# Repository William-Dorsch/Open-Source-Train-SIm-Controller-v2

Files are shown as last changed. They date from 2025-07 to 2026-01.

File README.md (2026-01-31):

# Open-Source-Train-SIm-Controller-v2

After 9 months I finally made a custom train sim controller I'm happy with, so here's a framework on how to build your own

Attached in this repo are both the files (stl and fbx) of my current design, as well as the scripts neccesary to make them work
(and perhaps documentation on how to make your own scripts for your own projects in the future)

### PRELIMINARY BUILD GUIDE ###
https://docs.google.com/document/d/1KSgfsF_5sMxbXlPAzv2AgdFZr4h-Y06j3LuT_041sC8/edit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<br>

# Hardware
You can either use my current design (based off of a North American desktop setup), or venture into CAD and make your own
FOr my design, you will need the following materials:<br/>
- Arduino Leonardo (or anything that has the usb serial whatever interface) <br/>
- Breadboard, jumper wires, other miscellanious wires to connect things (i use 30 gauge, anything smaller tha 18 could probably work) <br/>
- 50 #4 1/2" screws to be safe (you can buy two boxes of 25 from Ace for 5 bucks<br/>
- 1 6mm ball bearing <br/>
- a couple pen springs will need to be sacrificed, 13mm length<br/>
- 4 5x2mm magnets are necessary for the reverser<br/>
- 4 potentiometers (digikey part #  PDB12-H4301-103BF-ND, I suggest buying a couple spares in case something goes wrong while oldering (ask me how I know))<br/>
- 1 cherry MX brown switch (you can find a pack of them for cheap on Amazon, this is for the bail off, if you don't use bail off then you don't need this)<br/>
- black filament for the housing, need like 600g of that, then you can use whatever other colors you want.  Shouldn't be more than a spool total for the other parts, I use light gray for the handles, gray for the underframe, and gold to fake the brass brake valve parts<br/>
- A printer with a 256cm cubed build volume.  It will get really tricky if you don't, the throttle housing barely fit on my printer (Bambu P1S) <br/>
- some small gauge wire to connect to the potentiometers, the rest is up to you to make<br/>
- a soldering iron<br/>
- some electrical tape (used for friction on the independent brake)<br/>
- something to be used as a counterweight on the levers (I used pinewood derby car weights and pennies, and just hot glued these in place)<br/>

You only need to print 1 of all the parts, EXCEPT FOR THE FOLLOWING<br/>
- 5x axleSupportTall.stl<br/>
- 3x potentiometerHolderTall.stl<br/>
- 2x reverserAxleSupport<br/>

You'll also need to print a reverser, such as this one: (print at 95% scale) https://makerworld.com/en/models/919480-locomotive-reverser#profileId-881394<br/>
(huge credit to this design it is exactly what I was looking for)<br/>
And you'll need 2 printed m5 bolts to allow the throttle and independent brake handles to pivot, such as: https://www.printables.com/model/48364-3d-printable-m5-hex-screw-and-nut

There are some images attached to show how to assemble it, i think you'll be able to figure it out.

# Software
There are a variety of scripts included with this project<br/>
- an arduino sketch to pass data over the serial<br/>
- an arduino keybind-based sketch (for RSU)<br/>
- a python script to interface with the run8 UDP<br/>
- a python script to send the serial data over a local TCP server, paired with a c# .exe to interface with train sim classic<br/>
So you will need the latest version of python installed on your computer, as well as the arduino IDE.

To use it with run8, load the serialInterface arduino file, and run the run8 python script.  Ensure the com port is set correctly in the python script (use VScode or whatever to edi tit)<br/>
To use with TSC, load the serialInterface arduino file, run the TSCinterface python script, and run the code from Program.cs via visual studio.  I'll get an exe in there eventually, again ensure the com port in python is set correctly<br/>
To use it with RSU, just load the RSU arduino script and that's it.

NOTE: you will need the serial and socket libraries for python.  Get them by running the following in your command prompt: <br/>
>pip install serial <br/>
>pip install socket <br/>

NOTE: The TSC script is currently programmed to be used with the Surliner CC Enhancement Pack.  The ControlIDs change from locomotive to locomotive.  Use the function GetControllerList(); to return the list of controls for your specific locomotive.  The index begins at 0, count up from there for the ID of each control.  Plug those into the variables at the top of the script.
If you run it from Visual Studio, you will need the NuGet System.IO.ports package installed (right click the project and go to manage NuGet packages in the solution explorer)

## Calibration
- The values in the arduino script are hard-coded but can be changed<br/>
- For the throttle, note the output from the throttle potentiometer at each notch, and put that into the notch centers array.  If the value varies, add a piece of electrical tape on the potentiometer to avoid wiggle between it and the axle<br/>
- for the dynamic brake, note the value right after the notch, and the value while fuily applied.  Use those in the mapping function.<br/>
- For the automatic brakes, you need to note the values at release, minimum application, full service, suppression, handle off, and emergency (the 6 notches).  Plug in the values from there.<br/>
- FOr the independent brakes, just note the fully released as well as the fully applied values, and apply those to the mapping function<br/>
- For the reverser, note the center and fwd / rvs values.  Choose something halfway between the center and extremes to plug into the function.<br/>

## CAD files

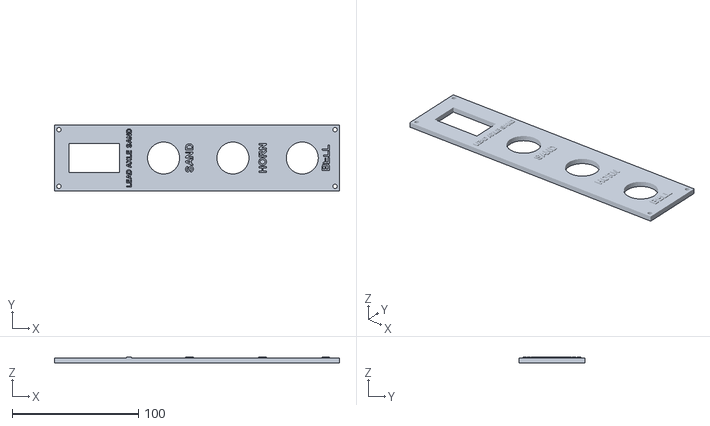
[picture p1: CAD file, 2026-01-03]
3d files/buttons/mainButtonPlate.stl
226.0 x 52.0 x 5.00

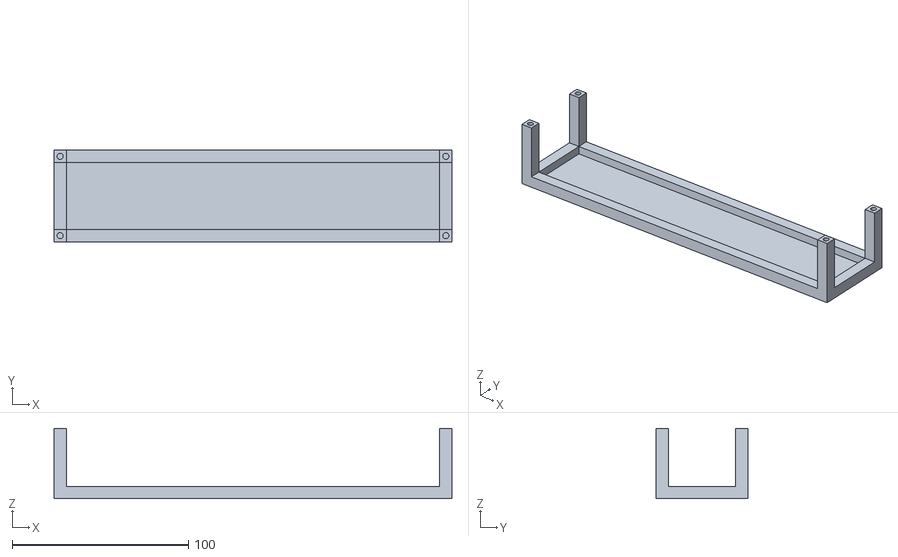
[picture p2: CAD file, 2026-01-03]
3d files/buttons/mainButtonbase.stl
226.0 x 52.0 x 39.9

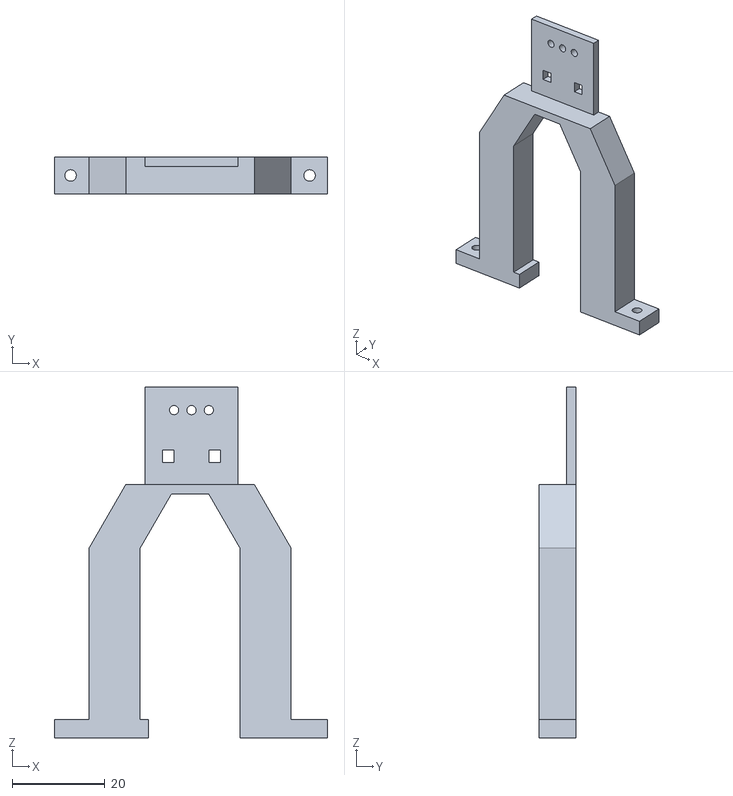
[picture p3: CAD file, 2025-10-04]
3d files/brake assembly/2x potentiometerHolderTall (1).stl
59.0 x 7.99 x 75.8

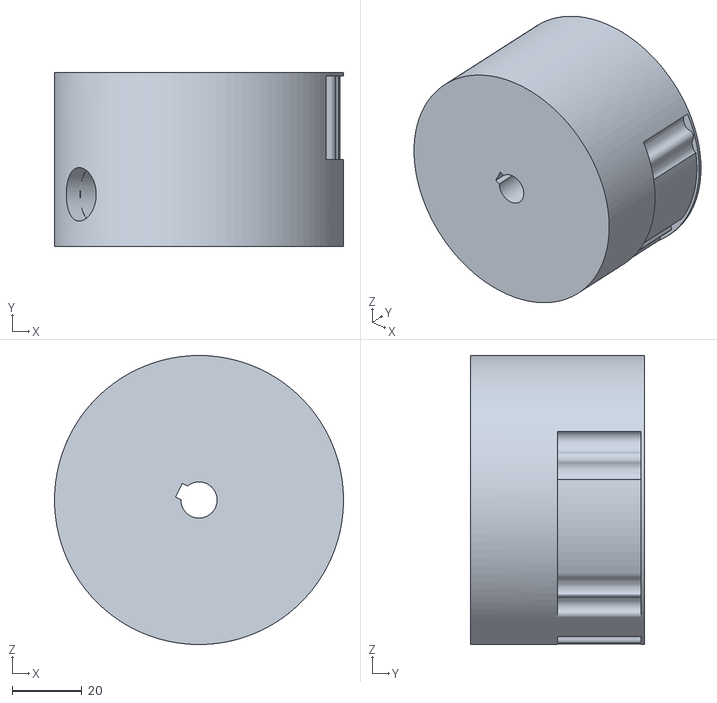
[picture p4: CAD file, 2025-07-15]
3d files/brake assembly/automatic brake/automaticBrakeWheel.stl
83.0 x 50.0 x 83.0

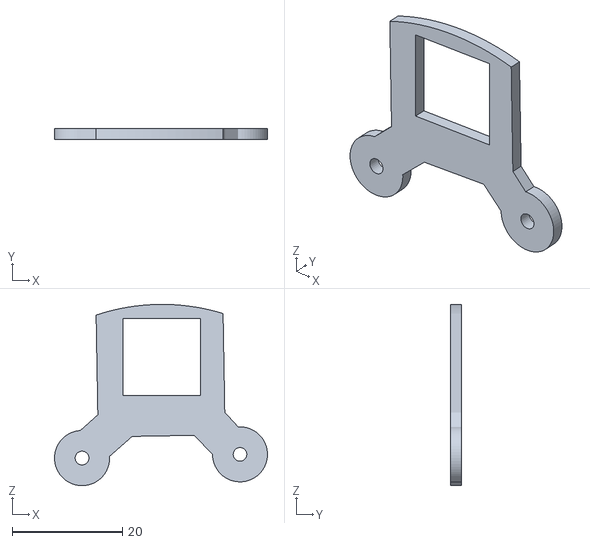
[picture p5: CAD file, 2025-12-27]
3d files/brake assembly/independent brake/bailOffBracket.stl
38.6 x 2.00 x 32.8

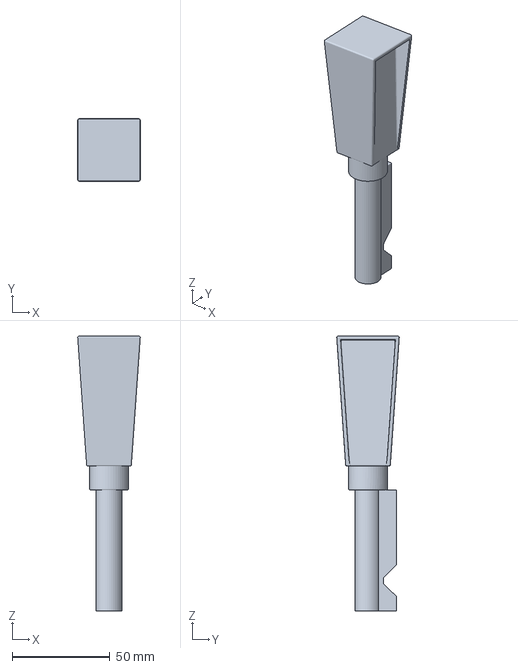
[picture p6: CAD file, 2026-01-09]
3d files/brass reverser 95.3mf
32.0 x 32.0 x 140.6 mm

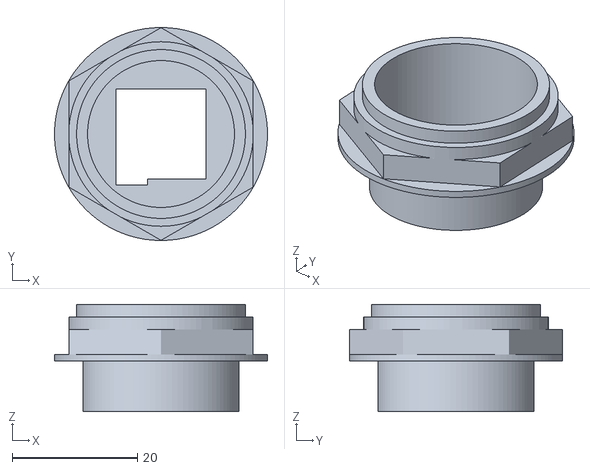
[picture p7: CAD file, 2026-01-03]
3d files/buttons/sandButtonHousing.stl
34.1 x 34.0 x 17.1

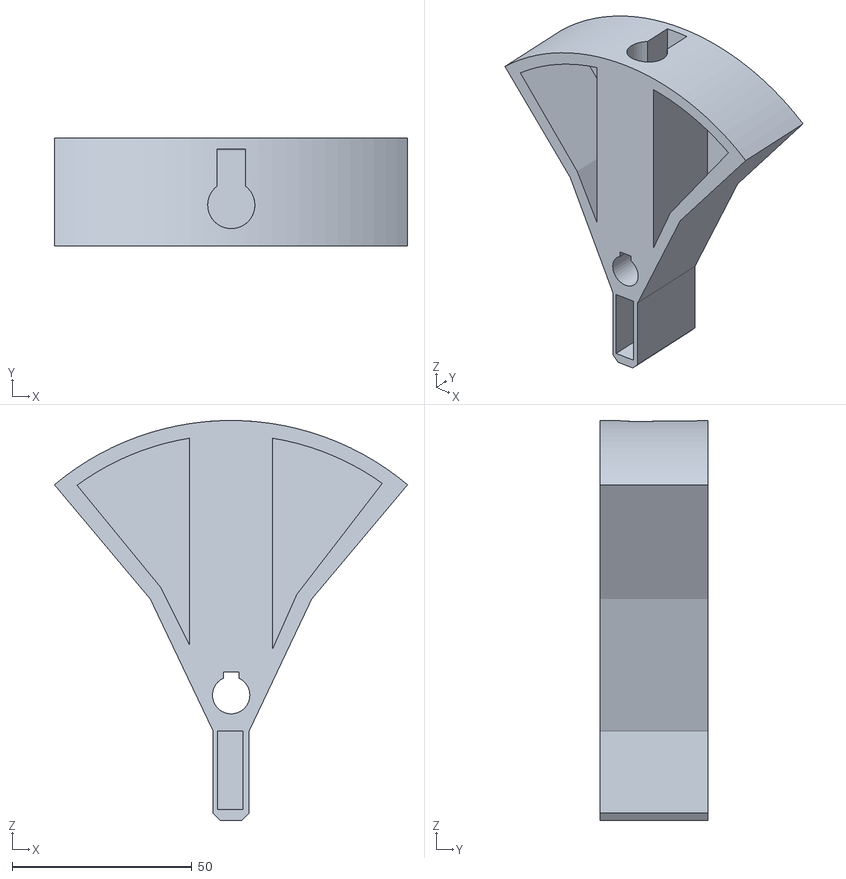
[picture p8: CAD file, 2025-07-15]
3d files/throttle assembly/reverser/reverserWheel.stl
98.3 x 30.0 x 111.4

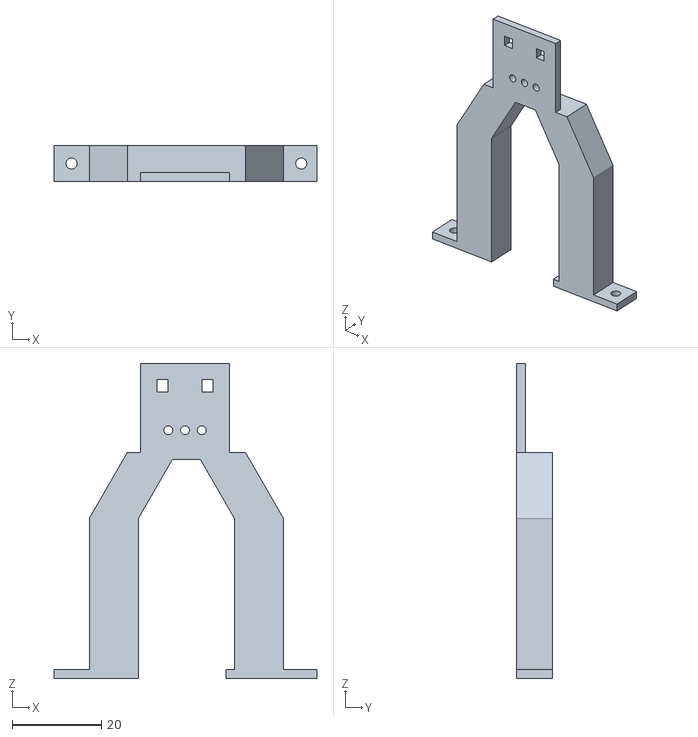
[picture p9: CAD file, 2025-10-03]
3d files/throttle assembly/throttle/1x potentiometerHolderTall.stl
59.0 x 7.99 x 70.8

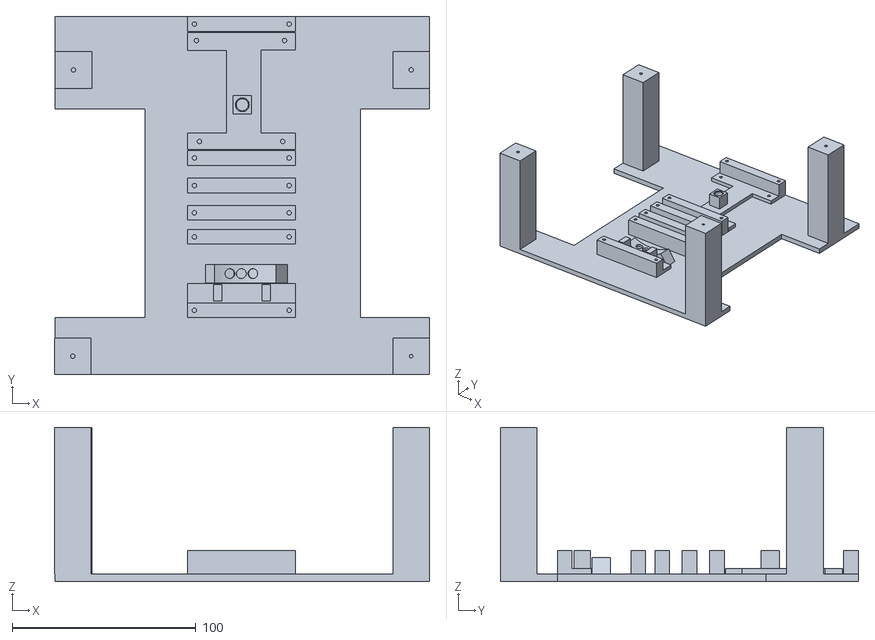
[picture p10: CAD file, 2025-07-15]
3d files/throttle assembly/throttleFrame.stl
204.3 x 195.1 x 84.0

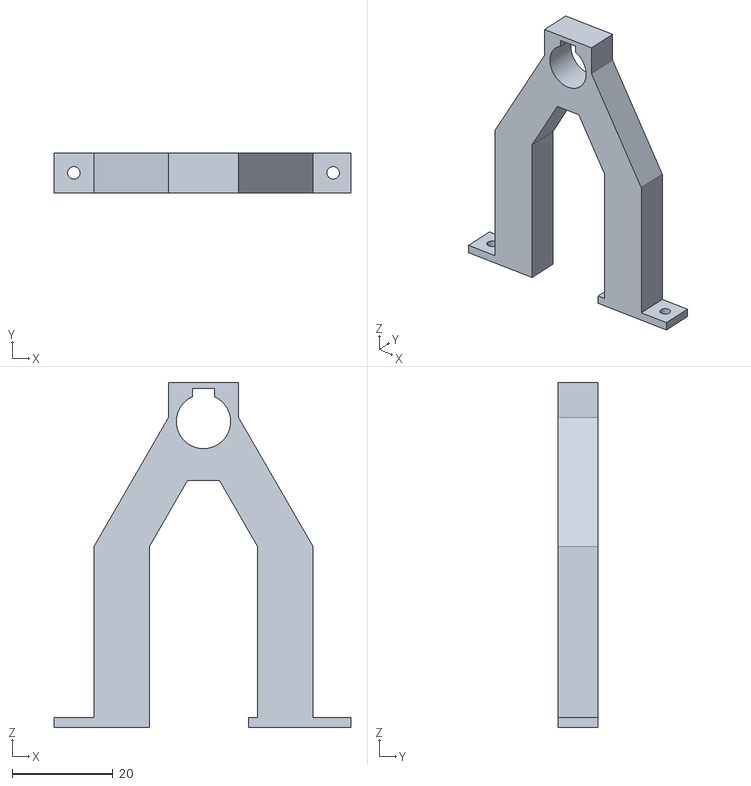
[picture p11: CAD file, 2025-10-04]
3d files/1x axleSupportTall.stl
59.0 x 8.06 x 68.6

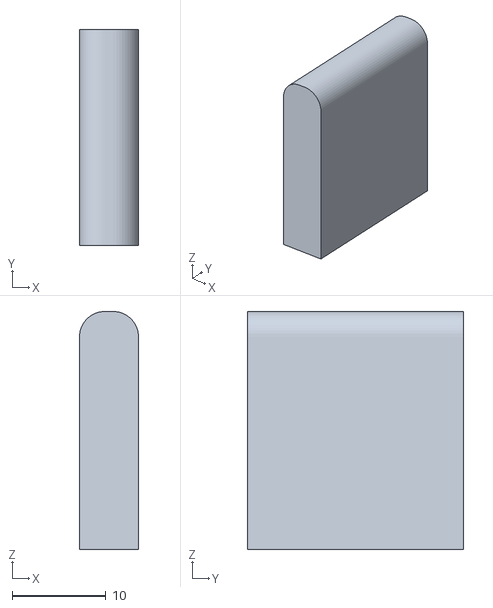
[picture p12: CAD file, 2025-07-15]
3d files/brake assembly/automatic brake/automaticBrakeNotch.stl
6.30 x 23.0 x 25.4

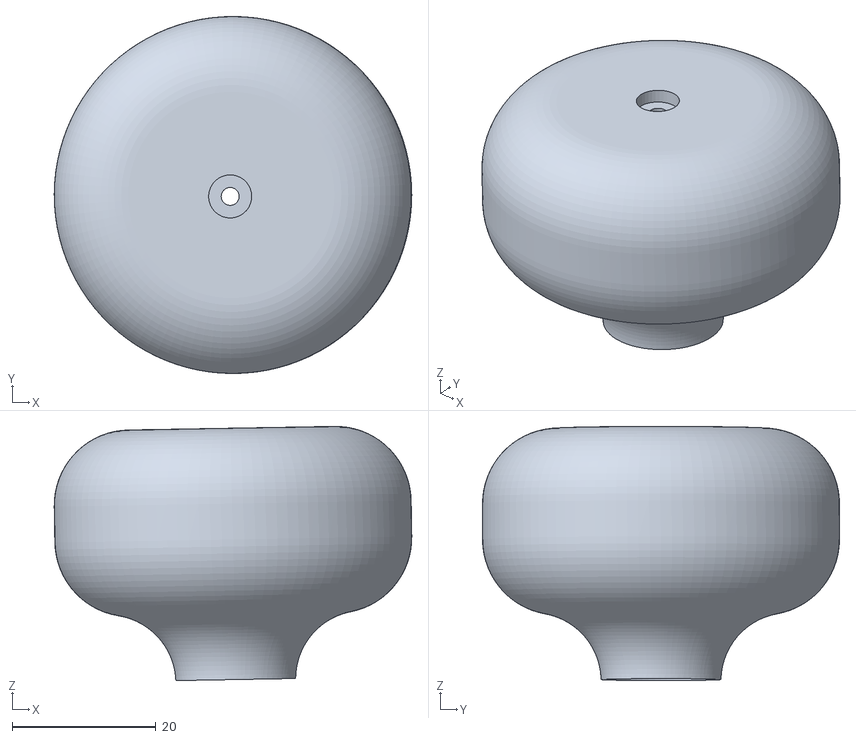
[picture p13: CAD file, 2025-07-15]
3d files/brake assembly/independent brake/independentBrakeHandle.stl
49.8 x 49.7 x 35.4

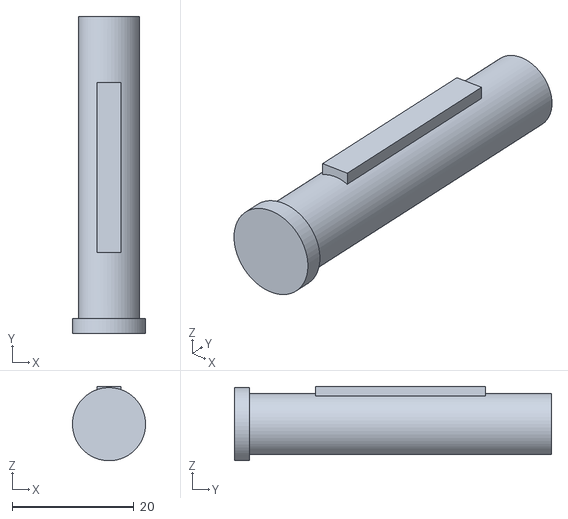
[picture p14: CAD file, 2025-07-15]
3d files/throttle assembly/reverser/reverserAxle.stl
12.0 x 52.0 x 12.2

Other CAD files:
3d files/brake assembly/4x axleSupportTall.stl
3d files/throttle assembly/throttle/1x axle support tall.stl
3d files/throttle assembly/throttleHousing.stl
3d files/1x potentiometerHolderTall.stl
3d files/brake assembly/30A-CDW frame.stl
3d files/brake assembly/30A-CDW housing.stl
3d files/brake assembly/automatic brake/automaticBrakeAxle.stl
3d files/brake assembly/automatic brake/automaticBrakeHandle.stl
3d files/brake assembly/automatic brake/automaticBrakeHandleShaft.stl
3d files/brake assembly/independent brake/bail off dummy bracket.stl
3d files/brake assembly/independent brake/independentBrakeAxle.stl
3d files/brake assembly/independent brake/independentBrakeHandleShaft.stl
3d files/brake assembly/independent brake/independentBrakeWheel.stl
3d files/buttons/bellButton.stl
3d files/buttons/hornButton.stl
3d files/buttons/hornButtonHousing.stl
3d files/buttons/leadAxleHousing.stl
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

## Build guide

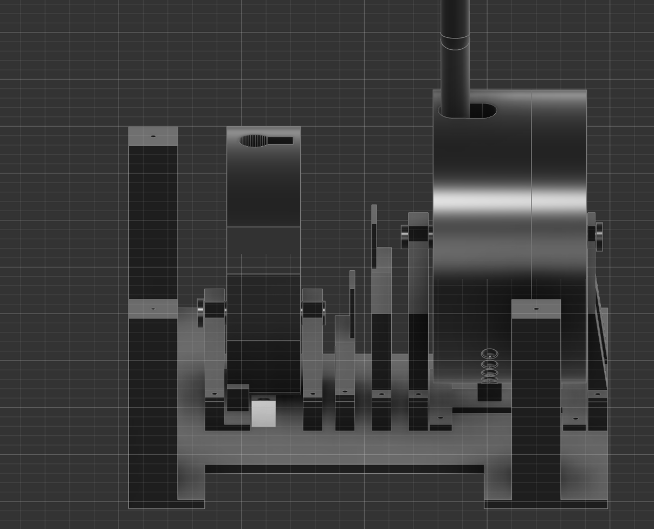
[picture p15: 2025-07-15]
3d files/throttle assembly/theottle assembly.png

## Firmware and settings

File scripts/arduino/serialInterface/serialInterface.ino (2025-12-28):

// pin mappings
const int bell = 5;
const int bail = 4;
const int sandMomentary = 3;
const int sandOn = 3;
const int sandOff = 7;
const int autoBrake = A0;
const int indyBrake = A1;
const int throttle = A3;
const int reverser = A4;
const int horn = 0;

// initializing udp variables
int sandState = 0;
int bellStateUDP = 0;
int hornStateUDP = 0;
int sandStateUDP = 0;
int automaticBrakePositionUDP = 0;
int sandToggleLogic = 0;
int autoValue = 0;
int mappedValue = 0;
int throttlePositionUDP = 0;
int throttlePosition = 0;  // Potentiometer value
int throttleNotch = 0;     // Calculated throttle notch (0-8)
int independentBrakePositionUDP = 0;
int independentBrakeBailUDP = 0;
int indyValue = 0;
int indyMappedValue = 0;
int notchCenters[9] = {475, 506, 535, 565, 594, 625, 654, 682, 704};
int dynoMappedValue = 0;
int reverserStateUDP = 0;
int dynamicBrakePositionUDP = 0;

// Track previous throttle position to determine direction
int previousThrottlePosition = 0;
bool increasingThrottle = true;
unsigned long autoHighStartTime = 0; // time when autoValue first >= 650
bool autoHighTimerRunning = false;   // track if timer is running
const unsigned long holdDuration = 500; // 500 ms
int autoMappedValue = 0;
void setup() {
  // put your setup code here, to run once:
  pinMode(bell, INPUT_PULLUP);
  pinMode(bail, INPUT_PULLUP);
  pinMode(sandMomentary, INPUT_PULLUP);
  pinMode(autoBrake, INPUT);
  pinMode(indyBrake, INPUT);
  pinMode(throttle, INPUT);
  pinMode(reverser, INPUT);
  pinMode(horn, INPUT_PULLUP);
  Serial.begin(9600);
}

void loop() {
  autoValue = analogRead(autoBrake);  // Read the potentiometer value (0 to 1023)
  // ignore all the commented stuff, everything works as is I swear
  //Serial.println(autoValue);
   //Map the potentiometer value to the range 0-255, with 360 -> 0 and 585 -> 255
  //mappedValue = map(autoValue, 405, 650, 0, 255);
  //Serial.println(analogRead(A3));
   //Constrain the output to stay within the 0-255 range
  //automaticBrakePositionUDP = constrain(mappedValue, 0, 255);
  int autoMappedValue;
/*
  if (autoValue >= 650) {
    autoMappedValue = 255;
  } else if (autoValue >= 600 && autoValue <= 640) {
    autoMappedValue = 254;
  } else if (autoValue > 555 && autoValue < 605) {
    // Smooth transition from 250 to 254 between 556 and 604
    autoMappedValue = map(autoValue, 556, 604, 251, 253);
  } else if (autoValue >= 405 && autoValue <= 555) {
    autoMappedValue = map(autoValue, 405, 555, 0, 250);
  } else {
    autoMappedValue = 0; // Below 405
  }
  automaticBrakePositionUDP = constrain(autoMappedValue, 0, 255);
*/
  if (autoValue >= 750) {
    if (!autoHighTimerRunning) {
      autoHighStartTime = millis();
      autoHighTimerRunning = true;
    }

    if (millis() - autoHighStartTime >= holdDuration) {
      autoMappedValue = 255;
    } else {
      // Not yet 500ms, keep previous value or set to transitional value
      autoMappedValue = 254; // or a temp value if needed
    }
  } else {
    autoHighTimerRunning = false; // reset timer if condition breaks

    if (autoValue >= 700 && autoValue < 750) {
      autoMappedValue = 254;
    } else if (autoValue >= 580 && autoValue < 700) {
      autoMappedValue = 253;
    } else if (autoValue >= 545 && autoValue < 580) {
      autoMappedValue = 252;
    } else if (autoValue >= 345 && autoValue < 545) {
      autoMappedValue = map(autoValue, 345, 545, 1, 252);
    } else {
      autoMappedValue = 0; // Below 405
    }
  }

  automaticBrakePositionUDP = constrain(autoMappedValue, 0, 255);
  //Serial.println(automaticBrakePositionUDP);
  indyValue = analogRead(indyBrake);

  indyMappedValue = map(indyValue, 635, 315, 0, 255);
  //Serial.println(indyValue);
  independentBrakePositionUDP = constrain(indyMappedValue, 0, 255);

  if (indyValue > 515){
    independentBrakeBailUDP = 1;
  } else {
    independentBrakeBailUDP = 0;
  }
  // Read potentiometer value
    throttlePosition = analogRead(throttle);  // Replace A0 with your throttle pin

    // Determine which notch the throttle is in
    int minDifference = abs(throttlePosition - notchCenters[0]);
    throttleNotch = 0;

    for (int i = 1; i < 9; i++) {
        int difference = abs(throttlePosition - notchCenters[i]);
        if (difference < minDifference) {
            minDifference = difference;
            throttleNotch = i;
        }
    }

    // Set throttlePositionUDP based on notch
    // this can definately be simplified but it works rn so I won't touch it
    switch (throttleNotch) {
        case 0:
            throttlePositionUDP = 152;
            throttlePositionUDP = 0;
            break;
        case 1:
            throttlePositionUDP = 128;
            throttlePositionUDP = 1;
            break;
        case 2:
            throttlePositionUDP = 129;
            throttlePositionUDP = 2;
            break;
        case 3:
            throttlePositionUDP = 132;
            throttlePositionUDP = 3;
            break;
        case 4:
            throttlePositionUDP = 133;
            throttlePositionUDP = 4;
            break;
        case 5:
            throttlePositionUDP = 142;
            throttlePositionUDP = 5;
            break;
        case 6:
            throttlePositionUDP = 143;
            throttlePositionUDP = 6;
            break;
        case 7:
            throttlePositionUDP = 134;
            throttlePositionUDP = 7;
            break;
        case 8:
            throttlePositionUDP = 135;
            throttlePositionUDP = 8;
            break;
    }
    
    
    
  // dynamic brake logic
  int dynoValue = analogRead(throttle);  
  //Serial.println(dynoValue);
  //Map the potentiometer value to the range 0-255, with 360 -> 0 and 585 -> 255
  dynoMappedValue = map(dynoValue, 400, 210, 0, 255);
  //Constrain the output to stay within the 0-255 range
  dynamicBrakePositionUDP = constrain(dynoMappedValue, 0, 255);

  
  // reverser logic
  int reverserPotentiometer = analogRead(reverser);
  if (reverserPotentiometer < 500){ 
    reverserStateUDP = 0;
  } else if (reverserPotentiometer > 545){
    reverserStateUDP = 255;
  } else {
    reverserStateUDP = 128;
  }

  // horn logic
  int hornState = digitalRead(horn);
  if (hornState == LOW) {
    hornStateUDP = 1;
  } else {
    hornStateUDP = 0;
  }
  
  // logic only works for run8 atm (and tsc since I fixed the code over in the c# script)
  int bellState = digitalRead(bell);
  if (bellState == LOW) {
    bellStateUDP = 1;
  } else {
    bellStateUDP = 0;
  }

  // logic only works for run8 atm (and tsc since I fixed the code over in the c# script)
  int bailState = digitalRead(bail);
  if (bailState == LOW) {
    independentBrakeBailUDP = 1;
  } else {
    independentBrakeBailUDP = 0;
  }

  /*
  // former toggling sand logic, however I don't use it anymore
  if (digitalRead(sandOn == LOW)){
    sandToggleLogic = 1;
  } else if (digitalRead(sandOff) == LOW){
    sandToggleLogic = 0;
  }

  if (sandToggleLogic == 0){
    if (digitalRead(sandMomentary) == LOW){
      sandStateUDP = 1;
    } else {
      sandStateUDP = 0;
    }
  } else if (sandToggleLogic == 1){
    sandStateUDP = 1;
  }
  */

  // momentary sander logic
  if (digitalRead(sandMomentary) == LOW){
    sandStateUDP = 1;
  } else {
    sandStateUDP = 0;
  } 
  
  // sending data over the serial
  Serial.print("RS:");
  Serial.print(reverserStateUDP);
  Serial.print(",TH:");
  Serial.print(throttlePositionUDP);
  Serial.print(",DB:");
  Serial.print(dynamicBrakePositionUDP);
  Serial.print(",IB:");
  Serial.print(independentBrakePositionUDP);
  Serial.print(",AB:");
  Serial.print(automaticBrakePositionUDP);
  Serial.print(",IL:");
  Serial.print(independentBrakeBailUDP);
  Serial.print(",HR:");
  Serial.print(hornStateUDP);
  Serial.print(",BL:");
  Serial.print(bellStateUDP);
  /*
  // headlight controls if you want to use them
  Serial.println(",HLF:");
  Serial.print(frontHeadlightUDP);
  Serial.print(",HLR:");
  Serial.print(rearHeadlightUDP);

  // Alerter data if you want to use it
  Serial.print(",AL:");
  Serial.print(alerterPressedUDP);
  */
  Serial.print(",SD:");
  Serial.println(sandStateUDP);

  delay(50);

}

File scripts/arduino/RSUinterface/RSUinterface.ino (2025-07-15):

#include <Keyboard.h>

const int buzzer = 2;
const int sandOn = 6;
const int sandMomentary = 5;
const int sandOff = 7;
const int door = 10;
const int bell = 5;
const int horn = 4;
const int reverser = A4;
const int throttle = A3;
const int brake = A0;
const int debounceDelay = 15; // Increased delay for debouncing
unsigned long lastBellPress = 0;

int sandState = 0;
int lastThrottlePosition = -1; // Initialize to an invalid notqqqqwwensure first reading is registered

// Define potentiometer center values for each notch
const int notchCenters[] = {475, 506, 535, 565, 594, 625, 654, 682, 704};
const int numNotches = sizeof(notchCenters) / sizeof(notchCenters[0]);
bool eBrakeActivated = false; // Flag to check if emergency brake has been activated
// Define a tolerance range around each notch center
const int tolerance = 10;

int lastBrakePosition = -1; // Initialize to an invalid position to ensure the first reading is registered

// Define potentiometer limits
const int brakeMin = 325; // Fully released
const int brakeMax = 580; // Fully applied
const int eBrakeThreshold = 750; // Emergency brake activation threshold

void setup() {
  // put your setup code here, to run once:
  pinMode(2, INPUT_PULLUP);
  pinMode(3, INPUT_PULLUP);
  pinMode(4, INPUT_PULLUP);
  pinMode(5, INPUT_PULLUP);
  pinMode(6, INPUT_PULLUP);
  pinMode(7, INPUT_PULLUP);
  pinMode(8, INPUT_PULLUP);
  pinMode(9, INPUT_PULLUP);
  pinMode(10, INPUT_PULLUP);
  pinMode(11, INPUT_PULLUP);
  pinMode(A0, INPUT);
  pinMode(A1, INPUT);
  pinMode(A2, INPUT);
  Serial.begin(9600);
  Keyboard.begin(); // Initialize keyboard functionality
}

void loop() {
  // put your main code here, to run repeatedly:


  int potValue = analogRead(throttle); // Read potentiometer value
  //Serial.println(potValue);
  // Find the current throttle position based on the closest notch center
  int throttlePosition = -1;
  for (int i = 0; i < numNotches; i++) {
    if (potValue >= notchCenters[i] - tolerance && potValue <= notchCenters[i] + tolerance) {
      throttlePosition = i;
      break;
    }
  }

  // Only send keypress if throttle position has changed
  if (throttlePosition != -1 && throttlePosition != lastThrottlePosition) {
  while (throttlePosition > lastThrottlePosition) {
    Keyboard.press('w');
    delay(20);
    Keyboard.release('w');
    lastThrottlePosition++;  // Move toward the current position
  }

  while (throttlePosition < lastThrottlePosition) {
    Keyboard.press('s');
    delay(20);
    Keyboard.release('s');
    lastThrottlePosition--;  // Move toward the current position
  }
}


  int BpotValue = analogRead(brake); // Read potentiometer value
  Serial.println(BpotValue);

  // Map potentiometer range (238-648) to brake positions (0-20)
  int brakePosition = map(BpotValue, brakeMin, brakeMax, 0, 20);
  brakePosition = constrain(brakePosition, 0, 20); // Ensure brake position stays within bounds

  // Check for emergency brake activation
  if (BpotValue >= eBrakeThreshold && !eBrakeActivated) {
    Keyboard.press(KEY_BACKSPACE); // Apply emergency brake
    delay(50); // Hold key press briefly
    Keyboard.release(KEY_BACKSPACE);
    eBrakeActivated = true; // Set the flag to prevent repeated presses
  } 
  else if (BpotValue < eBrakeThreshold) {
    eBrakeActivated = false; // Reset flag if below threshold
  }

  // Check if brake position has changed
  if (brakePosition != lastBrakePosition) {
    if (brakePosition > lastBrakePosition) {
      for (int i = lastBrakePosition + 1; i <= brakePosition; i++) {
        Keyboard.press('e'); // Press 'e' for each increment
        delay(20);
        Keyboard.release('e');
        delay(10); // Short delay between keystrokes
      }
    } 
    else if (brakePosition < lastBrakePosition) {
      for (int i = lastBrakePosition - 1; i >= brakePosition; i--) {
        Keyboard.press('q'); // Press 'q' for each decrement
        delay(20);
        Keyboard.release('q');
        delay(10); // Short delay between keystrokes
      }
    }

    lastBrakePosition = brakePosition; // Update last brake position
  }


  delay(0); // Small delay to stabilize readings

  if (digitalRead(horn) == LOW){
    Keyboard.press('n');
  } else if (digitalRead(horn) == HIGH){
    Keyboard.release('n');
  }

  if (digitalRead(bell) == LOW) {
        if (millis() - lastBellPress > debounceDelay) {
            Keyboard.press('b');
            lastBellPress = millis();
        }
    } else {
        Keyboard.release('b');
    }
  /*
  if (digitalRead(sandOn) == LOW){
    digitalWrite(2, HIGH);
    sandState = 1;
  } else if (digitalRead(sandOff) == LOW){
    digitalWrite(2, LOW);
    sandState = 0;
  } 

  if (sandState == 1){
    Keyboard.press(KEY_LEFT_SHIFT);
  } else if (sandState == 0){
    Keyboard.release(KEY_LEFT_SHIFT);
  }

  if (sandState == 0){
    if (digitalRead(sandMomentary) == LOW){
    Keyboard.press(KEY_LEFT_SHIFT);
    } else if (digitalRead(sandMomentary) == HIGH){
    Keyboard.release(KEY_LEFT_SHIFT);
    }
  }
  */
  if (digitalRead(door) == LOW){
    Keyboard.press('t');
  } else if (digitalRead(door) == HIGH){
    Keyboard.release('t');
  }
  delay(1);
  


}

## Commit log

2026-01-08 Rename axleSupportTall.stl to 4x axleSupportTall.stl
    [4x axleSupportTall.stl]
2026-01-08 Rename potentiometerHolderTall (1).stl to 2x potentiometerHolderTall (1).stl
    [2x potentiometerHolderTall (1).stl]
2026-01-08 Rename axleSupportTall.stl to 1x axleSupportTall.stl
    [1x axleSupportTall.stl]
2026-01-08 Rename potentiometerHolderTall.stl to 1x potentiometerHolderTall.stl
    [1x potentiometerHolderTall.stl]
2026-01-08 Rename reverserAxleSupport.stl to 2x reverserAxleSupport.stl
    [2x reverserAxleSupport.stl]
2026-01-08 Rename potentiometerHolderShort.stl to 1x potentiometerHolderShort.stl
    [1x potentiometerHolderShort.stl]
2026-01-08 Rename axleSupportThin.stl to 1x axleSupportThin.stl
    [1x axleSupportThin.stl]
2026-01-08 Rename axle support tall.stl to 1x axle support tall.stl
    [1x axle support tall.stl]
